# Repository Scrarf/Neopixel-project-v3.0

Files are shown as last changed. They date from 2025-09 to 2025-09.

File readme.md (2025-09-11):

# (work in progress) Status: Hardware verification. 

# Introduction:
A dimmable RGBW LED controller that can be controlled with wifi or bluetooth. A constant current DC-DC buck converter provides stable current to all leds connected in series, up to 3A. Currently, it is programmed for 300mah by R22 current sensing resistor for the apropriate onboard 300mah LEDs.

# 3D render:
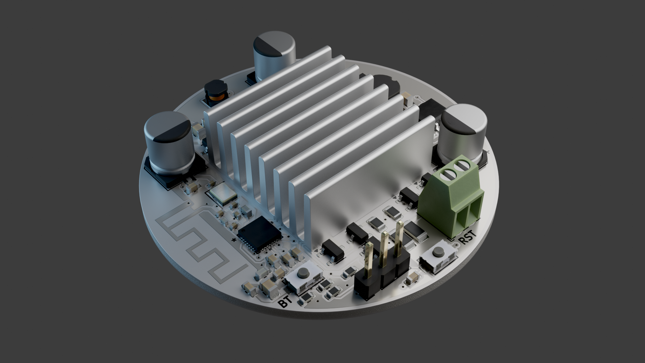
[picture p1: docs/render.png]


# Schematic:
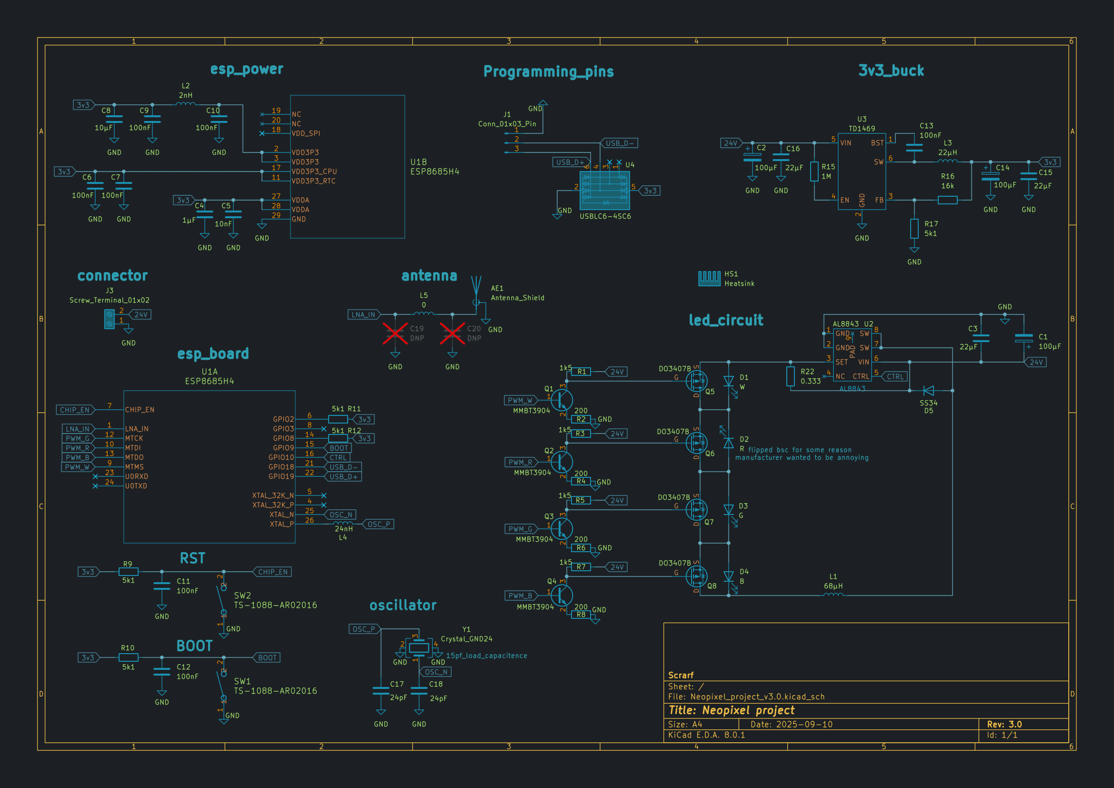
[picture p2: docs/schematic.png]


# Layout:
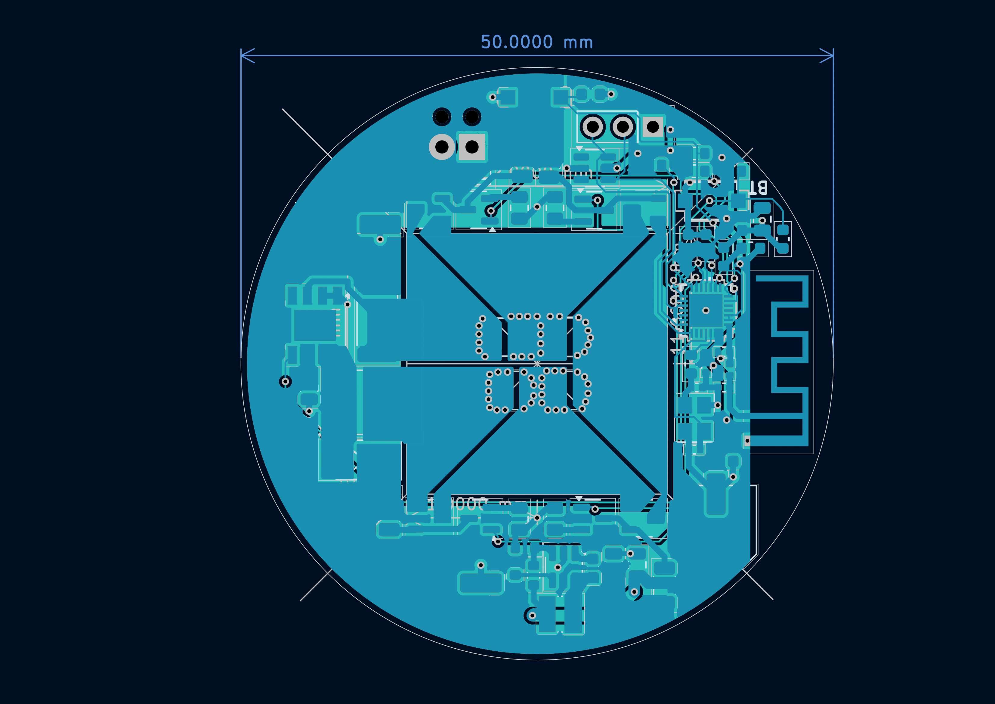
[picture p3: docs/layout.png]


# Bill of materials:

|Reference |Value |Datasheet |Footprint |Qty|PPU |DNP|
|---|---|---|---|---|---|---|
|C1,C2,C14 |100µF |https://www.lcsc.com/datasheet/C22383783.pdf |Capacitor_SMD:CP_Elec_6.3x7.7 |3  |0.0193| |
|C3,C15,C16 |22µF |https://www.lcsc.com/datasheet/C22367832.pdf |Capacitor_SMD:C_0805_2012Metric |3  |0.1158| |
|C4 |1µF |https://www.lcsc.com/datasheet/C15849.pdf |Capacitor_SMD:C_0603_1608Metric |1  |0.0038| |
|C5 |10nF |https://www.lcsc.com/datasheet/C60133.pdf |Capacitor_SMD:C_0402_1005Metric |1  |0.0009| |
|C6,C7,C9,C10,C11,C12,C13|100nF |https://www.lcsc.com/datasheet/C14663.pdf |Capacitor_SMD:C_0603_1608Metric |7  |0.0021| |
|C8 |10µF |https://www.lcsc.com/datasheet/C33546007.pdf |Capacitor_SMD:C_0805_2012Metric |1  |0.0178| |
|C17,C18 |24pF |https://www.lcsc.com/datasheet/C541435.pdf |Capacitor_SMD:C_0402_1005Metric |2  |0.0033| |
|C19,C20 |DNP |~ |Capacitor_SMD:C_0402_1005Metric |2  |0 |DNP|
|D1 |W |https://www.lcsc.com/datasheet/C7500126.pdf |LED_SMD:LED_PLCC_2835 |1  |0.069 | |
|D2 |R |https://www.lcsc.com/datasheet/C1322327.pdf |LED_SMD:LED_Luminus_MP-3030-1100_3.0x3.0mm |1  |0.1638| |
|D3 |G |https://www.lcsc.com/datasheet/C1322328.pdf |LED_SMD:LED_Luminus_MP-3030-1100_3.0x3.0mm |1  |0.1589| |
|D4 |B |https://www.lcsc.com/datasheet/C1322329.pdf |LED_SMD:LED_Luminus_MP-3030-1100_3.0x3.0mm |1  |0.0962| |
|D5 |SS34 |https://www.lcsc.com/datasheet/C8678.pdf |Diode_SMD:D_SMA |1  |0.0265| |
|HS1 |Heatsink |https://www.lcsc.com/datasheet/C286191.pdf |22x22x10 |1  |0.1324| |
|J1 |Conn_01x03_Pin |https://www.lcsc.com/datasheet/C5383112.pdf |Connector_PinHeader_2.54mm:PinHeader_1x03_P2.54mm_Vertical |1  |0.0105| |
|J3 |Screw_Terminal_01x02|https://www.lcsc.com/datasheet/C5188442.pdf |TerminalBlock_Phoenix:TerminalBlock_Phoenix_MPT-0,5-2-2.54_1x02_P2.54mm_Horizontal|1  |0.1513| |
|L1 |68µH |https://www.lcsc.com/datasheet/C2929435.pdf |Inductor_SMD:L_Ferrocore_DLG-0504 |1  |0.052 | |
|L2 |2nH |https://www.lcsc.com/datasheet/C395081.pdf |Inductor_SMD:L_0603_1608Metric |1  |0.0069| |
|L3 |22µH |https://www.lcsc.com/datasheet/C41408473.pdf |Inductor_SMD:L_Ferrocore_DLG-0302 |1  |0.0184| |
|L4 |24nH |https://www.lcsc.com/datasheet/C139271.pdf |Inductor_SMD:L_0603_1608Metric |1  |0.0064| |
|L5 |0 |https://www.lcsc.com/datasheet/C106231.pdf |Inductor_SMD:L_0402_1005Metric |1  |0.0006| |
|Q1,Q2,Q3,Q4 |MMBT3904 |https://www.lcsc.com/datasheet/C2762221.pdf |Package_TO_SOT_SMD:SOT-23 |4  |0.0095| |
|Q5,Q6,Q7,Q8 |DO3407B |https://www.lcsc.com/datasheet/C41367402.pdf |Package_TO_SOT_SMD:SOT-23-3 |4  |0.0271| |
|R1,R3,R5,R7 |1k5 |https://www.lcsc.com/datasheet/C2980089.pdf |Resistor_SMD:R_1206_3216Metric |4  |0.013 | |
|R2,R4,R6,R8 |200 |https://www.lcsc.com/datasheet/C3014166.pdf |Resistor_SMD:R_0805_2012Metric |4  |0.0156| |
|R9,R10,R11,R12,R17 |5k1 |https://www.lcsc.com/datasheet/C103696.pdf |Resistor_SMD:R_0603_1608Metric |5  |0.0009| |
|R15 |1M |https://www.lcsc.com/datasheet/C103216.pdf |Resistor_SMD:R_0603_1608Metric |1  |0.001 | |
|R16 |16k |https://www.lcsc.com/datasheet/C137788.pdf |Resistor_SMD:R_0603_1608Metric |1  |0.0012| |
|R22 |0.333 |https://www.lcsc.com/datasheet/C160932.pdf |Resistor_SMD:R_2512_6332Metric |1  |0.0488| |
|SW1,SW2 |TS-1088-AR02016 |https://www.lcsc.com/datasheet/C720477.pdf |TS-1088-AR02016:SW_TS-1088_XNP |2  |0.0415| |
|U1 |ESP8685H4 |https://www.lcsc.com/datasheet/C4944062.pdf |ESP8685:QFN284X4_EXP |1  |1.3435| |
|U2 |AL8843 |https://www.lcsc.com/datasheet/lcsc_datasheet_2412251103_Diodes-Incorporated-AL8843SP-13_C507866.pdf|Package_SO:Diodes_SO-8EP |1  |0.3568| |
|U3 |TD1469 |https://www.lcsc.com/datasheet/C2832208.pdf |Package_TO_SOT_SMD:TSOT-23-6 |1  |0.2999| |
|U4 |USBLC6-4SC6 |https://www.lcsc.com/datasheet/C19170931.pdf |Package_TO_SOT_SMD:SOT-23-6 |1  |0.0273| |
|Y1 |Crystal_GND24 |https://www.lcsc.com/datasheet/C501793.pdf |Crystal:Crystal_SMD_Abracon_ABM8AIG-4Pin_3.2x2.5mm |1  |0.0922| |

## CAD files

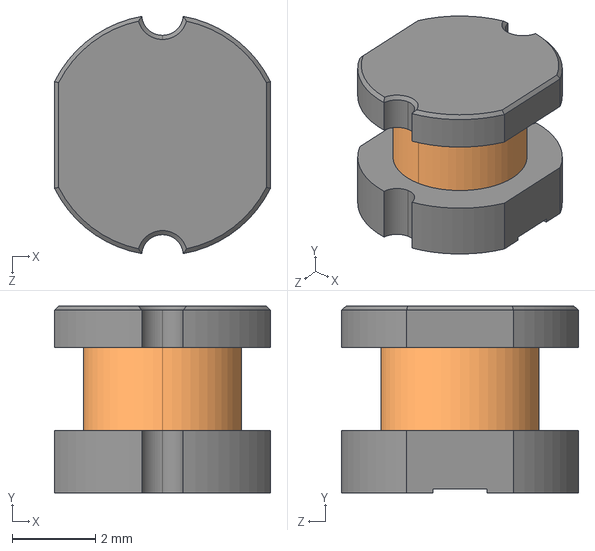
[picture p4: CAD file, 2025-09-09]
3d_models/DLG-0504-100.stp
5.20 x 4.50 x 5.71 mm

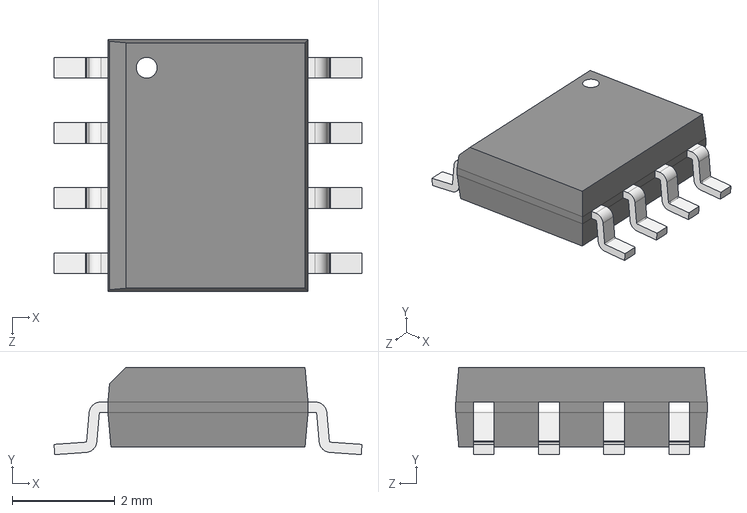
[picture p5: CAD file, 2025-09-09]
3d_models/AL8843Q.stp
6.00 x 1.70 x 4.90 mm

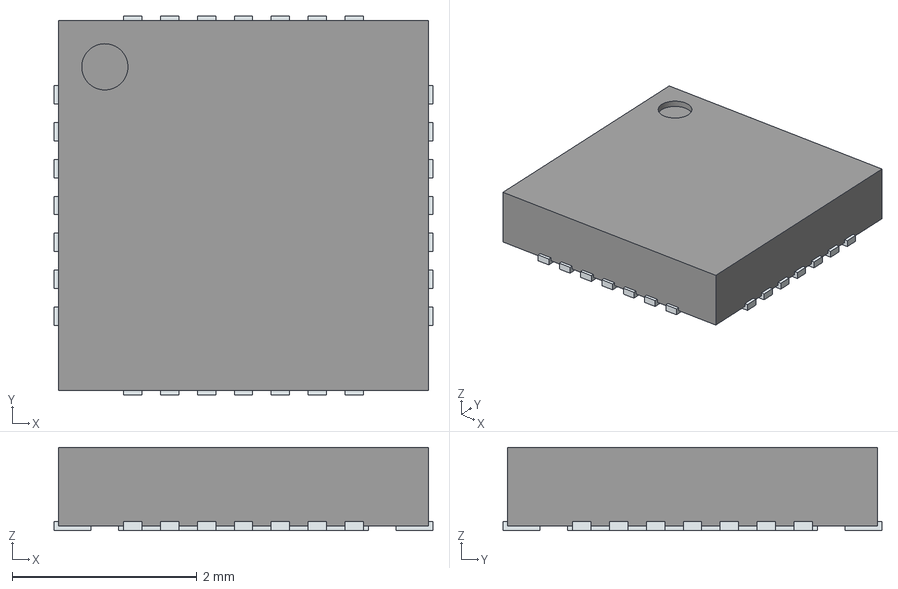
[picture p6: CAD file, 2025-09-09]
3d_models/ESP8685H2.stp
4.10 x 4.10 x 0.9 mm
ThermalPin
PinsArrayLR
PinsArrayTB

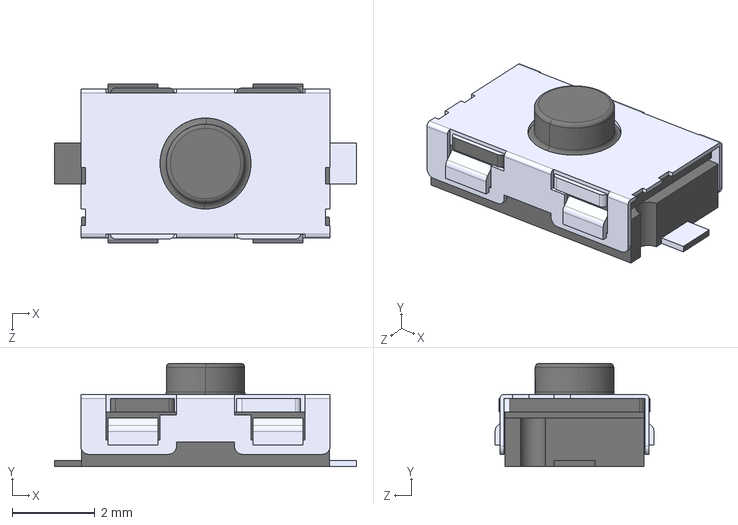
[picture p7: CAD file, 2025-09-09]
3d_models/KSR551GLFS.stp
7.30 x 2.50 x 3.84 mm

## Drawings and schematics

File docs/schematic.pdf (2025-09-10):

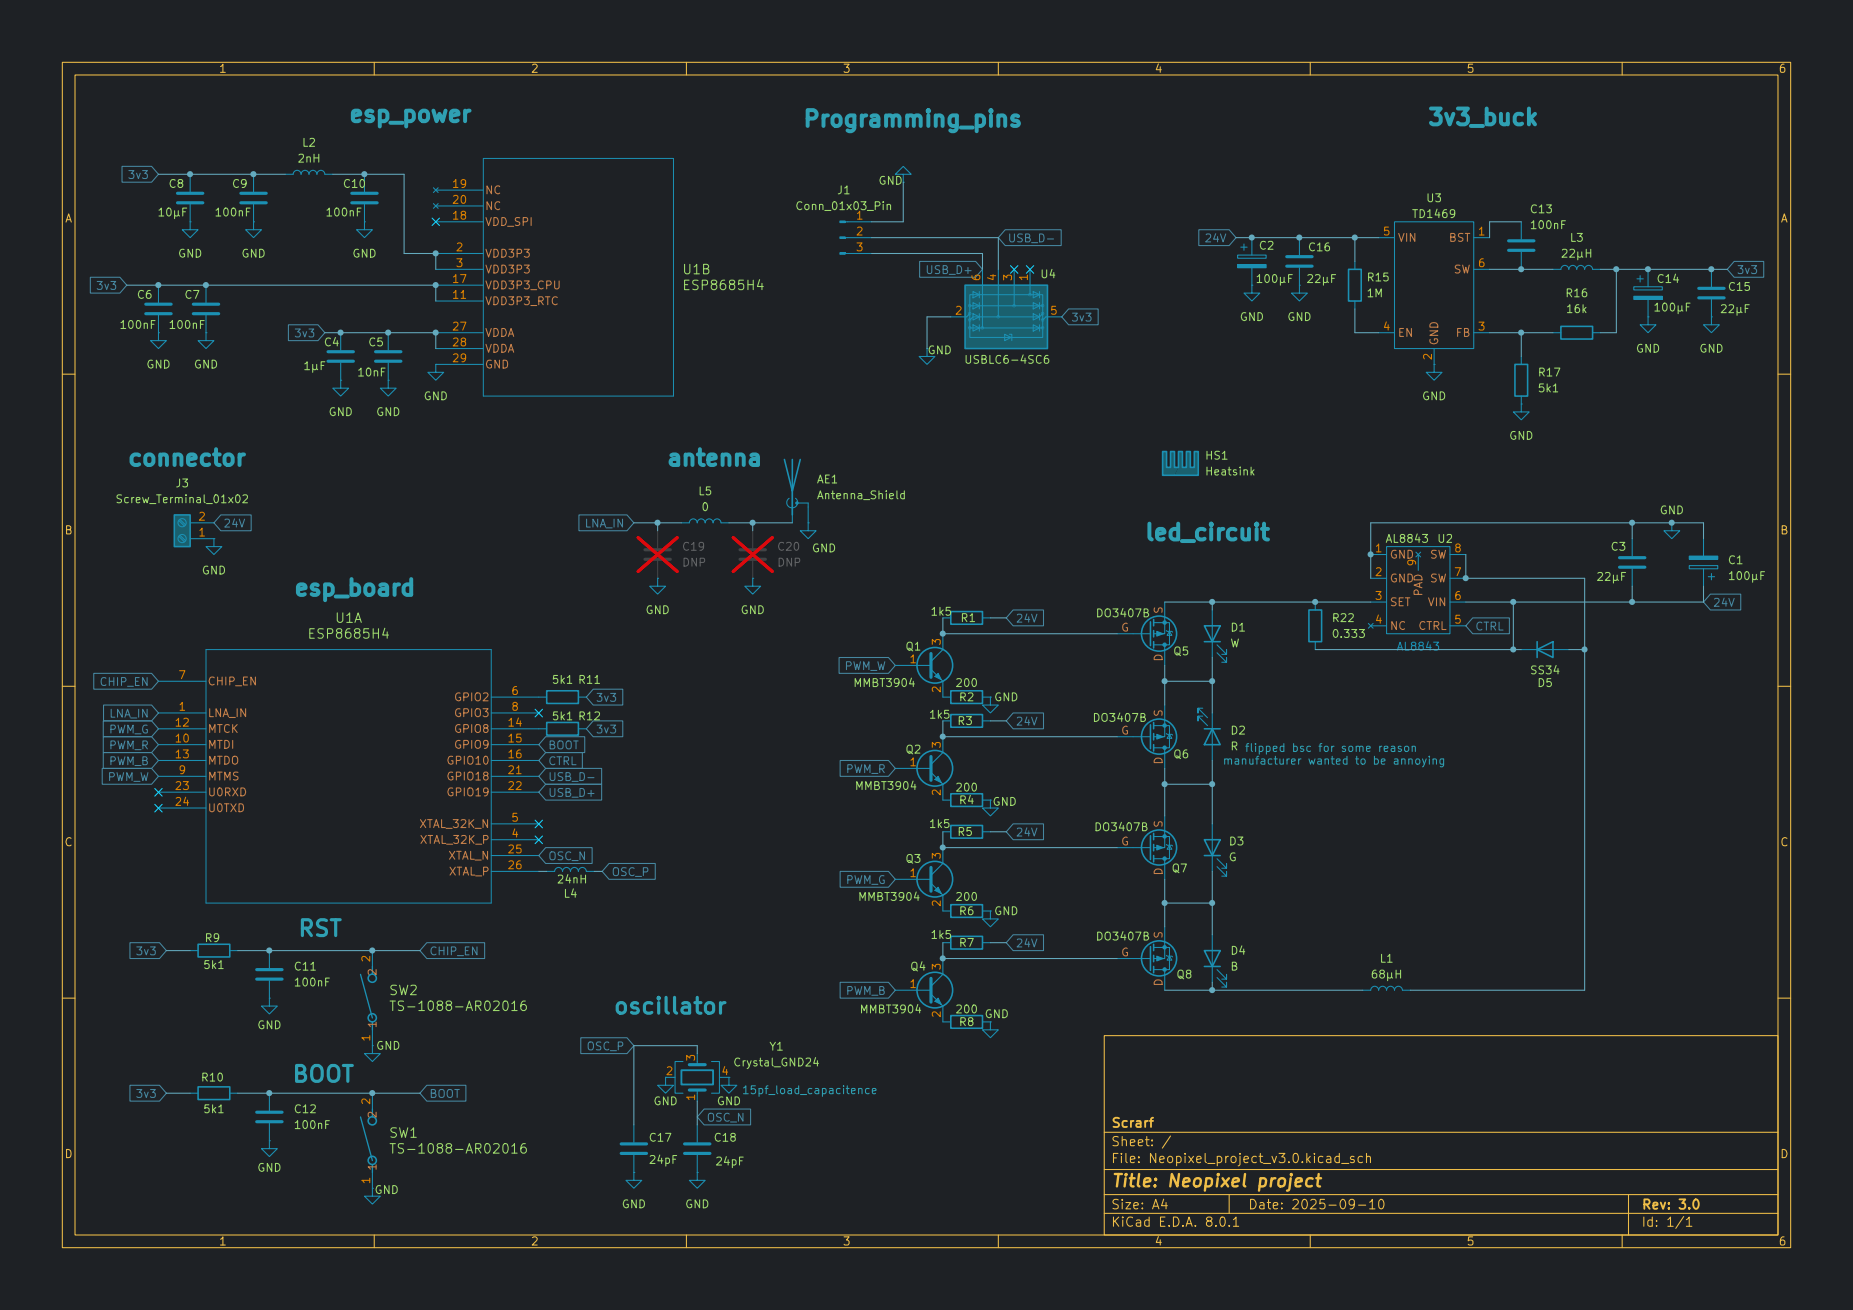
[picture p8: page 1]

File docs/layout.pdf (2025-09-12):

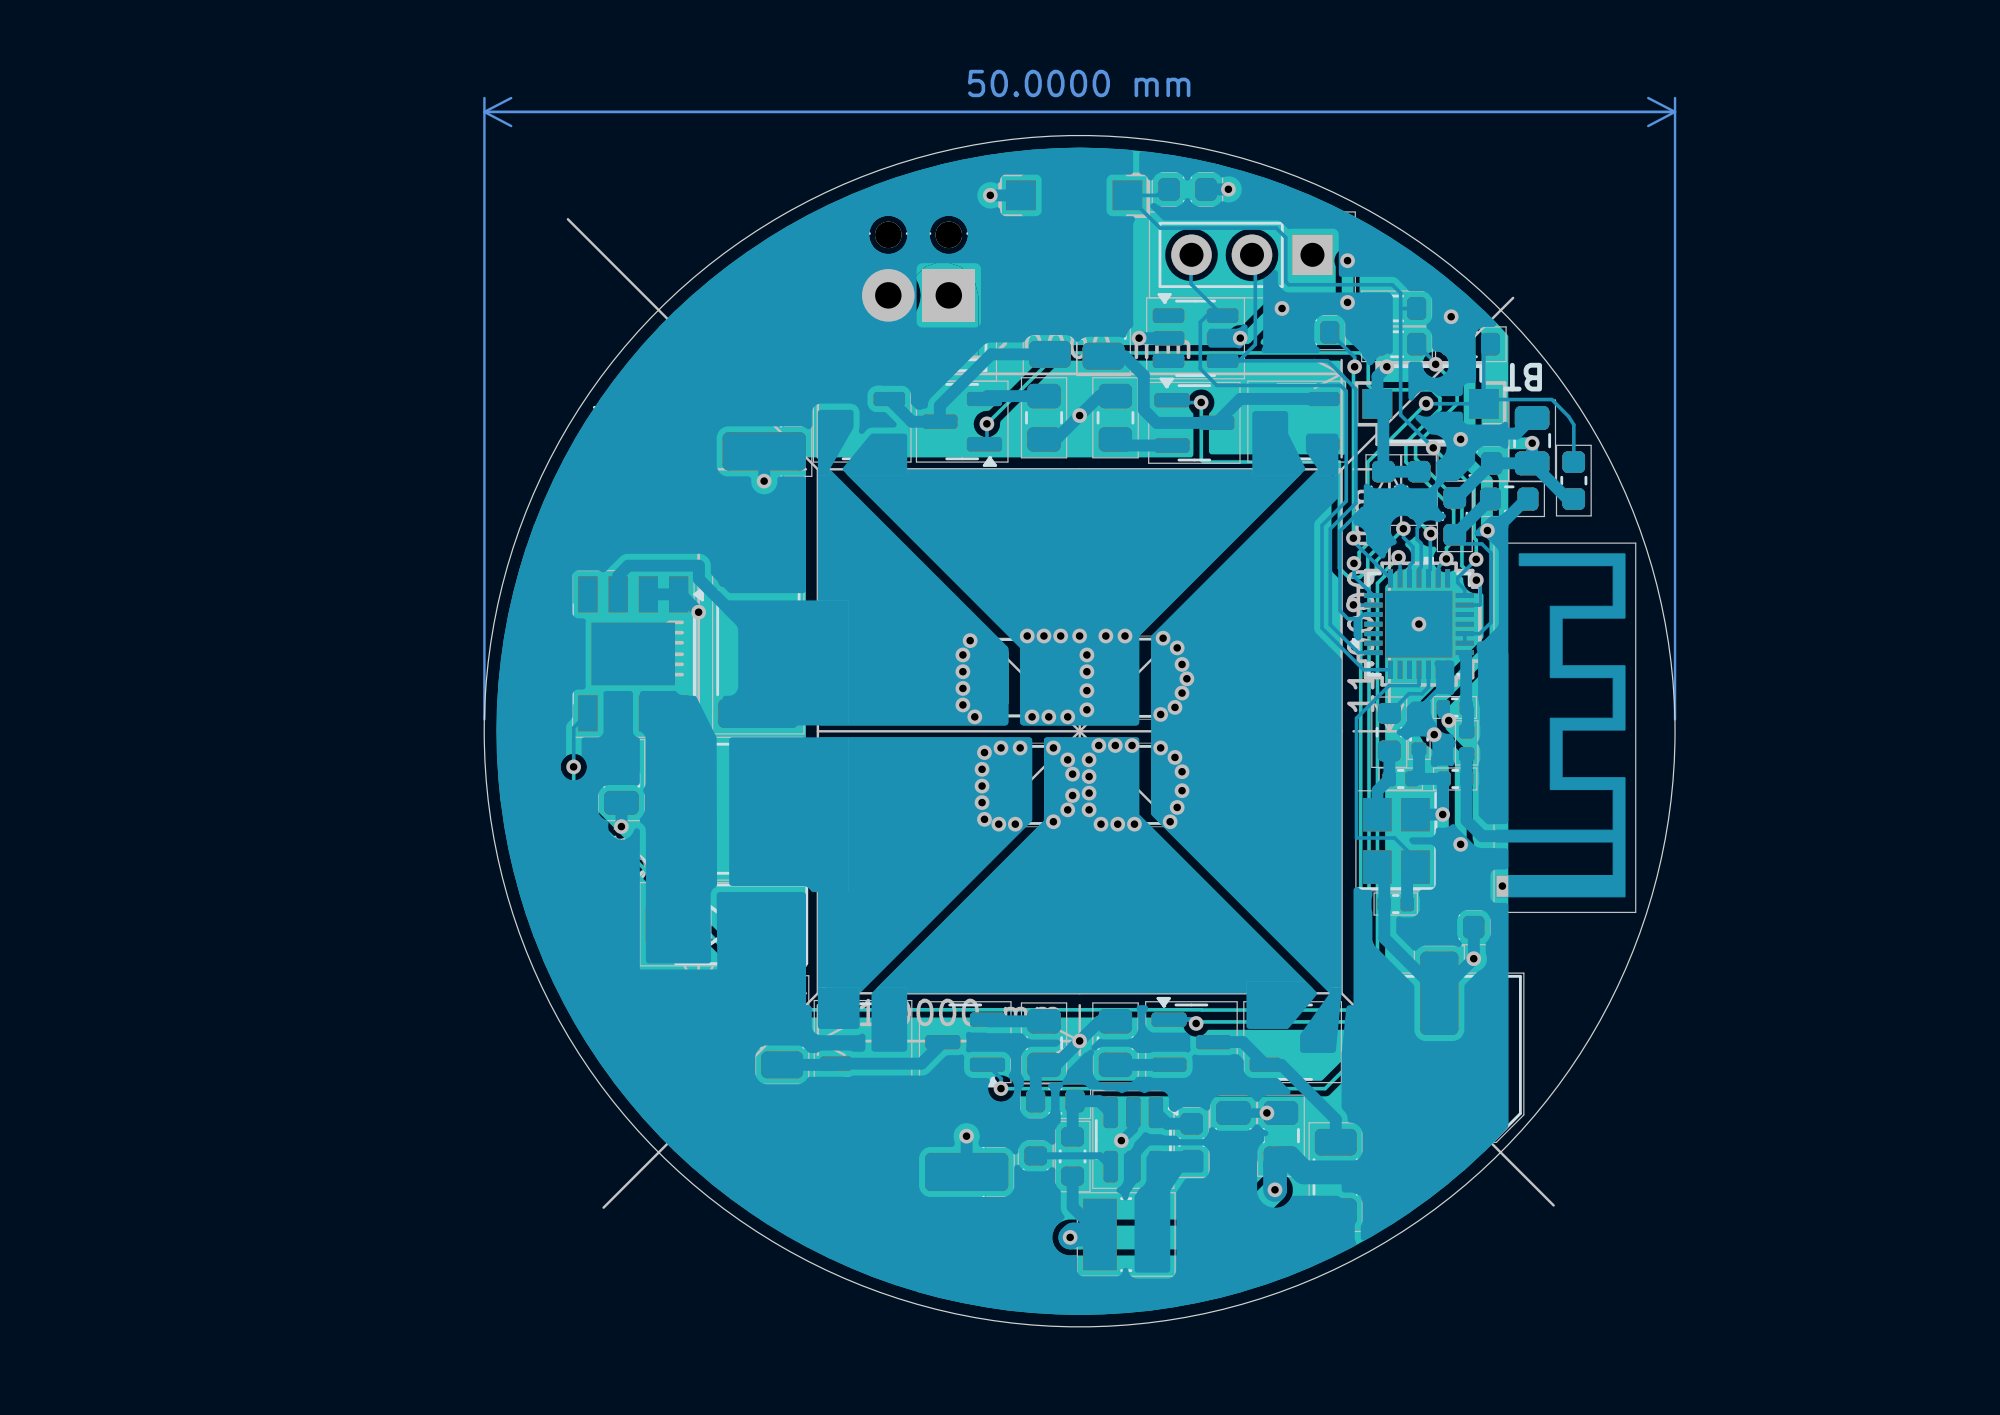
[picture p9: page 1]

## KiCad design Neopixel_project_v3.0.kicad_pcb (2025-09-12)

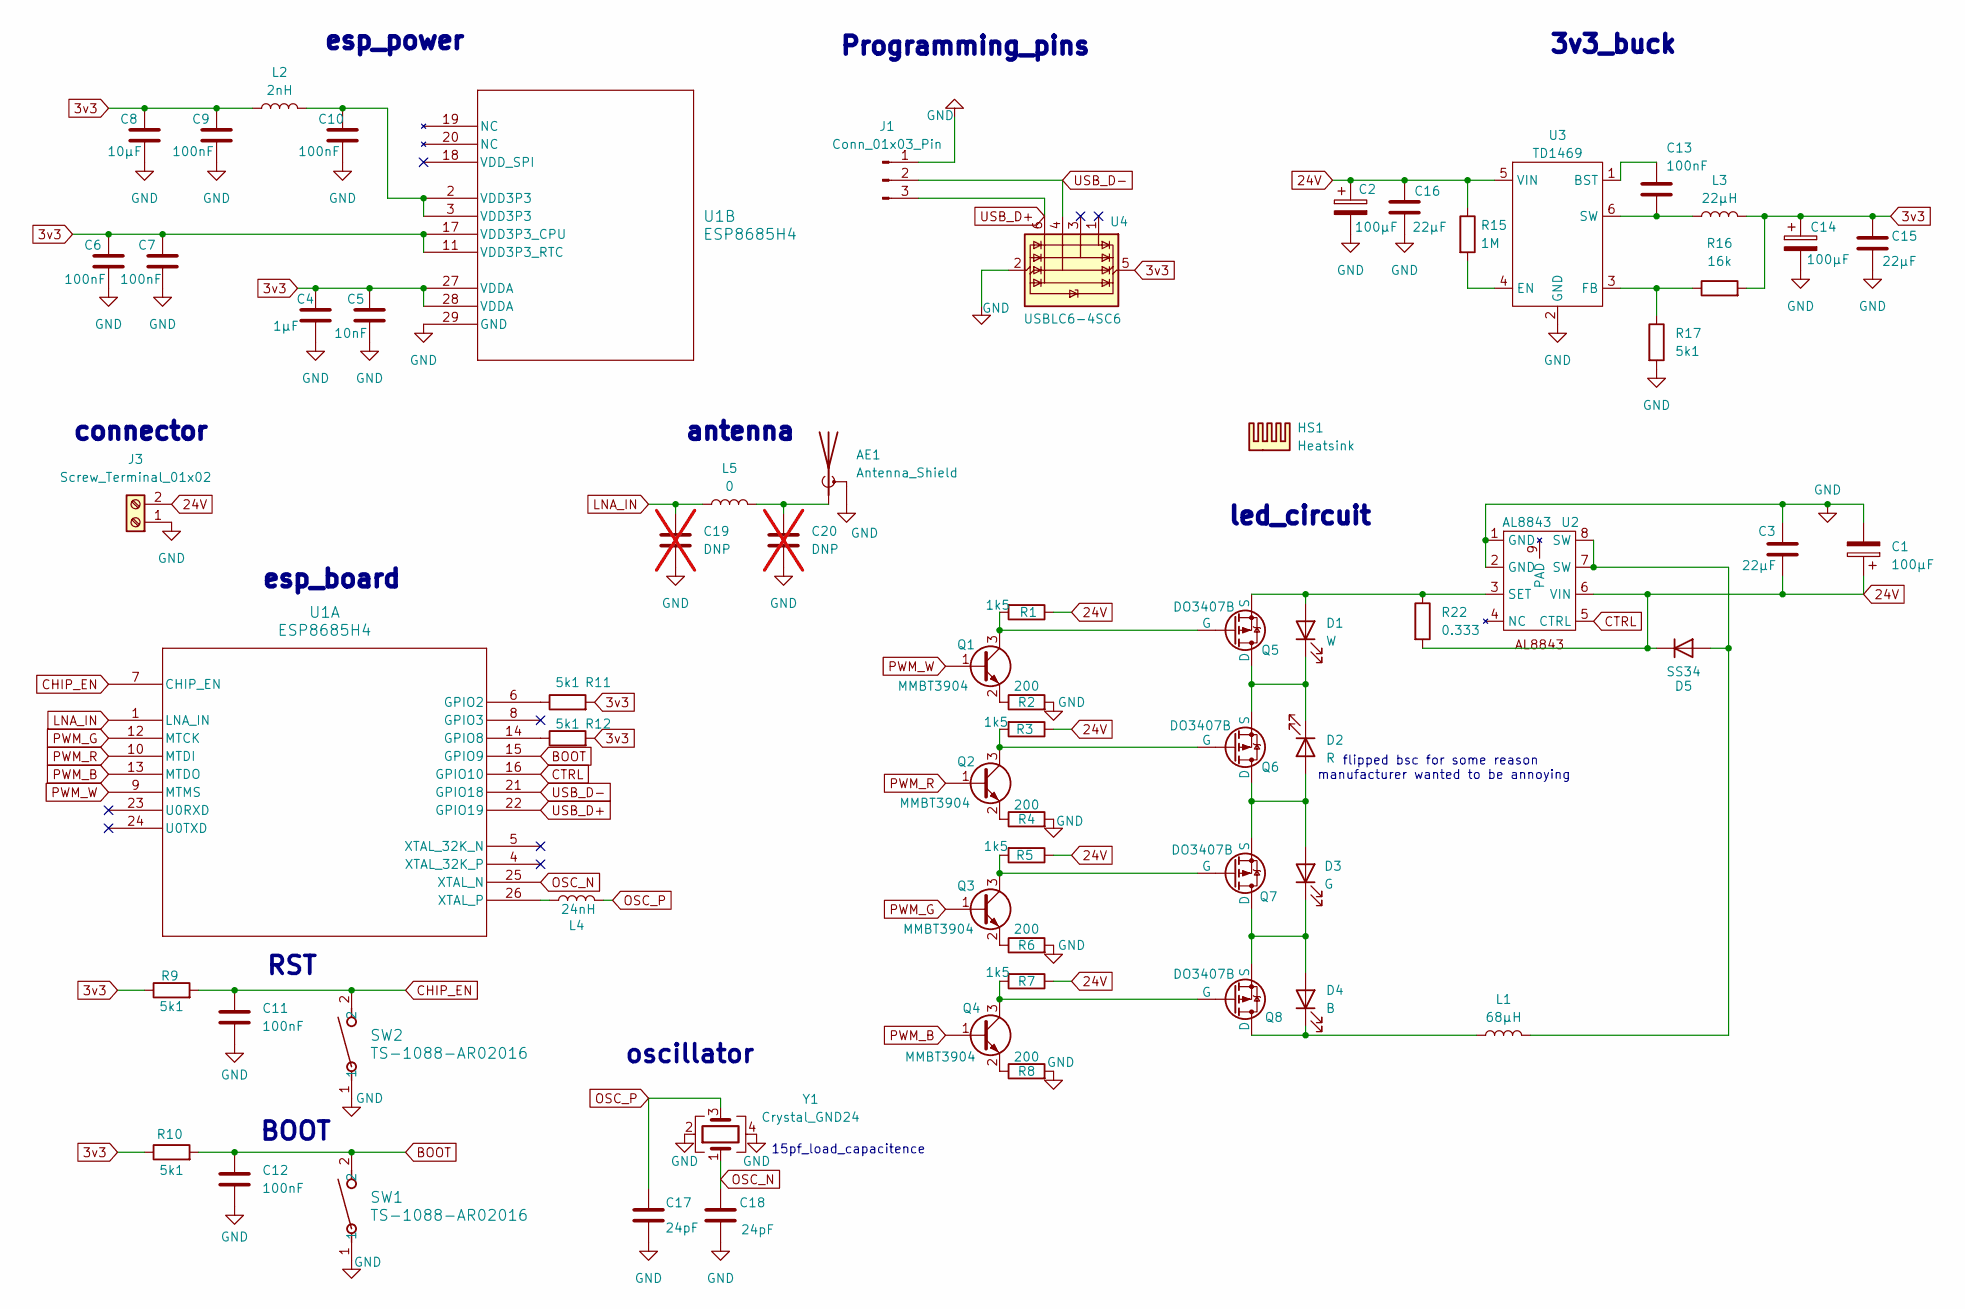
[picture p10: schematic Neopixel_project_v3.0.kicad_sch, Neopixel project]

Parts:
AE1: Antenna_Shield; Texas_SWRA117D_2.4GHz_Left
C1, C2, C14: 100µF; CP_Elec_6.3x7.7
C3, C15, C16: 22µF; C_0805_2012Metric
C4: 1µF; C_0603_1608Metric
C5: 10nF; C_0402_1005Metric
C6, C7, C9, C10, C11, C12, C13: 100nF; C_0603_1608Metric
C8: 10µF; C_0805_2012Metric
C17, C18: 24pF; C_0402_1005Metric
C19, C20: DNP; C_0402_1005Metric; not fitted
D1: W; LED_PLCC_2835
D2: R; LED_Luminus_MP-3030-1100_3.0x3.0mm
D3: G; LED_Luminus_MP-3030-1100_3.0x3.0mm
D4: B; LED_Luminus_MP-3030-1100_3.0x3.0mm
D5: SS34; D_SMA
HS1: Heatsink; 22x22x10
J1: Conn_01x03_Pin; PinHeader_1x03_P2.54mm_Vertical
J3: Screw_Terminal_01x02; TerminalBlock_Phoenix_MPT-0,5-2-2.54_1x02_P2.54mm_Horizontal
L1: 68µH; L_Ferrocore_DLG-0504
L2: 2nH; L_0603_1608Metric
L3: 22µH; L_Ferrocore_DLG-0302
L4: 24nH; L_0603_1608Metric
L5: 0; L_0402_1005Metric
Q1, Q2, Q3, Q4: MMBT3904; SOT-23
Q5, Q6, Q7, Q8: DO3407B; SOT-23-3
R1, R3, R5, R7: 1k5; R_1206_3216Metric
R2, R4, R6, R8: 200; R_0805_2012Metric
R9, R10, R11, R12, R17: 5k1; R_0603_1608Metric
R15: 1M; R_0603_1608Metric
R16: 16k; R_0603_1608Metric
R22: 0.333; R_2512_6332Metric
SW1, SW2: TS-1088-AR02016; SW_TS-1088_XNP
U1: ESP8685H4; QFN284X4_EXP
U2: AL8843; Diodes_SO-8EP
U3: TD1469; TSOT-23-6
U4: USBLC6-4SC6; SOT-23-6
Y1: Crystal_GND24; Crystal_SMD_Abracon_ABM8AIG-4Pin_3.2x2.5mm

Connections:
3v3: C4.1, C5.1, C6.1, C7.1, C8.1, C9.1, C14.1, C15.1, L2.1, L3.2, R9.1, R10.1, R11.2, R12.2, R16.2, U1.11 (VDD3P3_RTC), U1.17 (VDD3P3_CPU), U1.27 (VDDA), U1.28 (VDDA), U4.5 (VBUS)
24V: C1.1, C2.1, C3.2, C16.1, D5.1 (K), J3.2, R1.1, R3.1, R5.1, R7.1, R15.1, R22.2, U2.6 (VIN), U3.5 (VIN)
BOOT: C12.1, R10.2, SW1.2, U1.15 (GPIO9)
CHIP_EN: C11.1, R9.2, SW2.2, U1.7 (CHIP_EN)
CTRL: U1.16 (GPIO10), U2.5 (CTRL)
GND: AE1.2 (Shield), C1.2, C2.2, C3.1, C4.2, C5.2, C6.2, C7.2, C8.2, C9.2, C10.2, C11.2, C12.2, C14.2, C15.2, C16.2, C17.2, C18.2, C19.2, C20.2, J1.1, J3.1, R2.2, R4.2, R6.2, R8.2, R17.2, SW1.1, SW2.1, U1.29 (GND), U2.1 (GND), U2.2 (GND), U3.2 (GND), U4.2 (GND), Y1.2, Y1.4
LNA_IN: C19.1, L5.1, U1.1 (LNA_IN)
unnamed: AE1.1 (A), C20.1, L5.2
unnamed: C10.1, L2.2, U1.2 (VDD3P3), U1.3 (VDD3P3)
unnamed: D1.2 (A), Q5.3 (S), R22.1, U2.3 (SET)
unnamed: D1.1 (K), D2.1 (K), Q5.1 (D), Q6.3 (S)
unnamed: D2.2 (A), D3.2 (A), Q6.1 (D), Q7.3 (S)
unnamed: D3.1 (K), D4.2 (A), Q7.1 (D), Q8.3 (S)
unnamed: D4.1 (K), L1.1, Q8.1 (D)
unnamed: D5.2 (A), L1.2, U2.7 (SW), U2.8 (SW)
unnamed: Q1.3 (C), Q5.2 (G), R1.2
unnamed: Q1.2 (E), R2.1
unnamed: Q2.3 (C), Q6.2 (G), R3.2
unnamed: Q2.2 (E), R4.1
unnamed: Q3.3 (C), Q7.2 (G), R5.2
unnamed: Q3.2 (E), R6.1
unnamed: Q4.3 (C), Q8.2 (G), R7.2
unnamed: Q4.2 (E), R8.1
unnamed: R11.1, U1.6 (GPIO2)
unnamed: R12.1, U1.14 (GPIO8)
unnamed: L4.1, U1.26 (XTAL_P)
unnamed: C13.1, U3.1 (BST)
unnamed: R15.2, U3.4 (EN)
unnamed: R16.1, R17.1, U3.3 (FB)
unnamed: C13.2, L3.1, U3.6 (SW)
OSC_N: C18.1, U1.25 (XTAL_N), Y1.1
OSC_P: C17.1, L4.2, Y1.3
PWM_B: Q4.1 (B), U1.13 (MTDO)
PWM_G: Q3.1 (B), U1.12 (MTCK)
PWM_R: Q2.1 (B), U1.10 (MTDI)
PWM_W: Q1.1 (B), U1.9 (MTMS)
USB_D+: J1.3, U1.22 (GPIO19), U4.6 (I/O4)
USB_D-: J1.2, U1.21 (GPIO18), U4.4 (I/O3)

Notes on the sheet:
RST
esp_power
led_circuit
flipped bsc for some reason manufacturer wanted to be annoying
connector
3v3_buck
antenna
Programming_pins
15pf_load_capacitence
oscillator
BOOT
esp_board

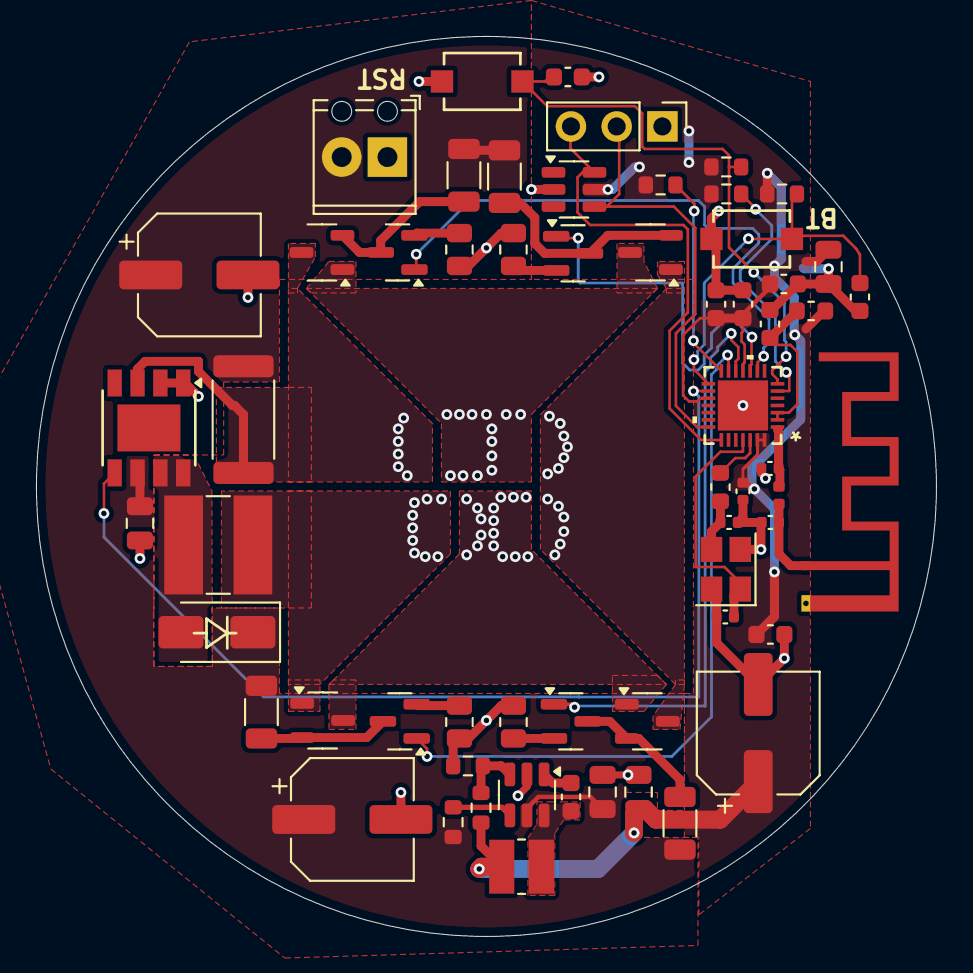
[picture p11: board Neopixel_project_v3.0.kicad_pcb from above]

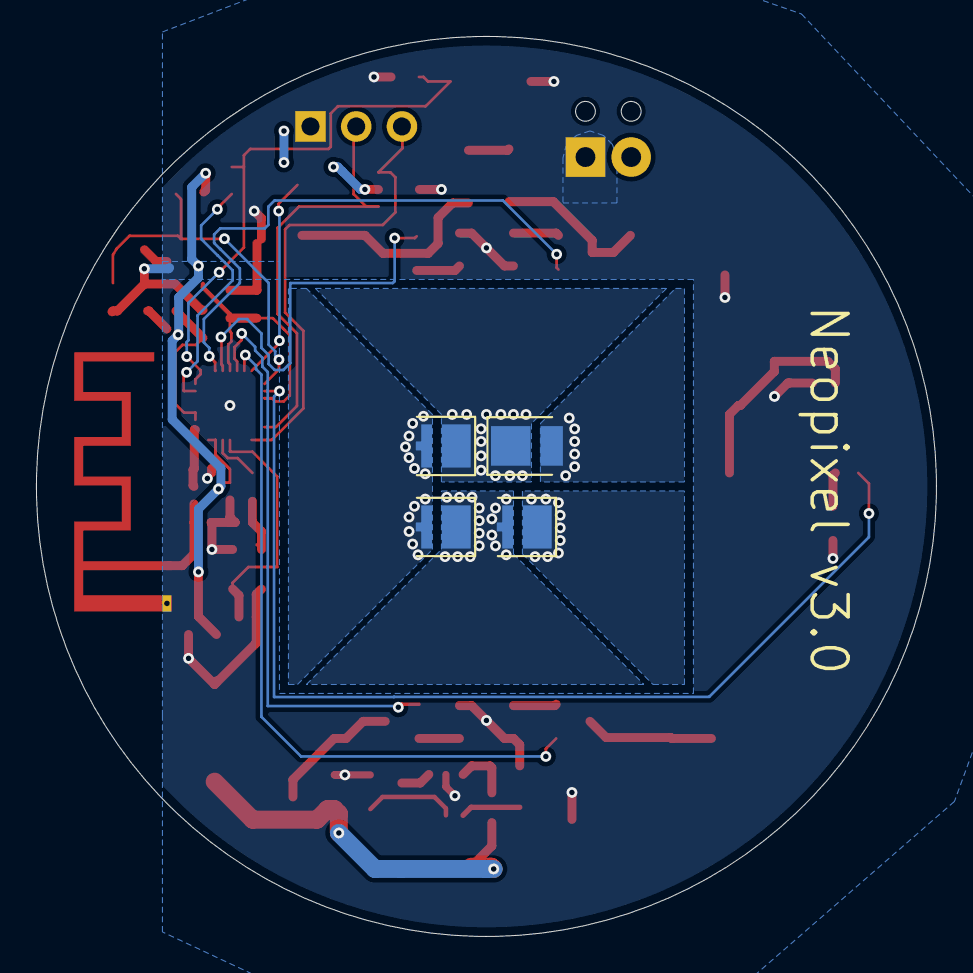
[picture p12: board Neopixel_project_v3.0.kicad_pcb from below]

Board: 2 copper layers, 50.0 x 50.0 mm, 64 parts (4 on the bottom side), 38 nets.

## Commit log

2025-09-07 remove bom.csv
    [bom.csv]
2025-09-09 snapshot save
    [Neopixel_project_v3.0.kicad_pcb, Neopixel_project_v3.0.kicad_sch]
2025-09-09 pcb finished
    [Neopixel_project_v3.0.kicad_pcb, Neopixel_project_v3.0.kicad_sch]
2025-09-09 pcb and 3d models finished
    [AL8843Q.stp, DLG-0504-100.stp, ESP8685H2.stp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]
2025-09-09 added bom.csv and buch of other changes
    [Neopixel_project_v3.0.kicad_pcb, Neopixel_project_v3.0.kicad_sch, bom.csv]
2025-09-09 added heatsink to bom
    [Neopixel_project_v3.0.kicad_sch, bom.csv]
2025-09-10 silkscreen removed and layout printed
    [Neopixel_project_v3.0.kicad_pcb, Neopixel_project_v3.0.kicad_sch]
2025-09-10 added gerber files
    [Neopixel_project_v3.0-B_Cu.gbr, Neopixel_project_v3.0-B_Mask.gbr, Neopixel_project_v3.0-B_Paste.gbr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]
2025-09-11 bom viewer
2025-09-12 updated gerber
    [Neopixel_project_v3.0-B_Cu.gbr, Neopixel_project_v3.0-B_Mask.gbr, Neopixel_project_v3.0-B_Paste.gbr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]
2025-09-12 updated render and silkscreen
    [Neopixel_project_v3.0.kicad_pcb]
